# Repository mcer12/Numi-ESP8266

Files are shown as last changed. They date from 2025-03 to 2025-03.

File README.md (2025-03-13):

# Numi-ESP8266
Numi is an open source ESP8266 numitron clock. It's designed to be as low profile as possible, powered using USB-PD.

**Wiki**  
Software-wise it is based on my Flora-ESP8266 project, so you can head over there for basic info.  
https://github.com/mcer12/Flora-ESP8266/wiki/

**Enclosure**  
You can find the designs in this repository inside "3D" folder or download them on printables  
https://www.printables.com/model/1228268

**Some things to note:**
1) This design is made with small footprint and ultra low-profile in mind, using only 3mm high components.
2) Using mostly modern and widely available components.
3) Can be completely sourced from LCSC (except for the VFDs and incadescent bulb) and partially assembled using JLCPCB assembly service.
4) CH340 with NodeMCU style auto-reset built-in for easy programming / debugging via USB-C
5) Each segment driven directly, not multiplexed
6) NTP based, no battery / RTC. Connect to wifi and you're done.
7) Simple and easy to set up, mobile-friendly web interface
8) diyHue and remote control support
9) 3 levels of brightness + optional low brightness night mode
10) No buttons design. Simple configuration portal is used for settings.
11) Daylight saving (summer time) support built in and super simple to set up.

**License:**  
GPL-3.0 License  
LGPL-2.1 License (modified SPI library)  
Mozilla Public License 2.0 (iro.js, https://github.com/jaames/iro.js)

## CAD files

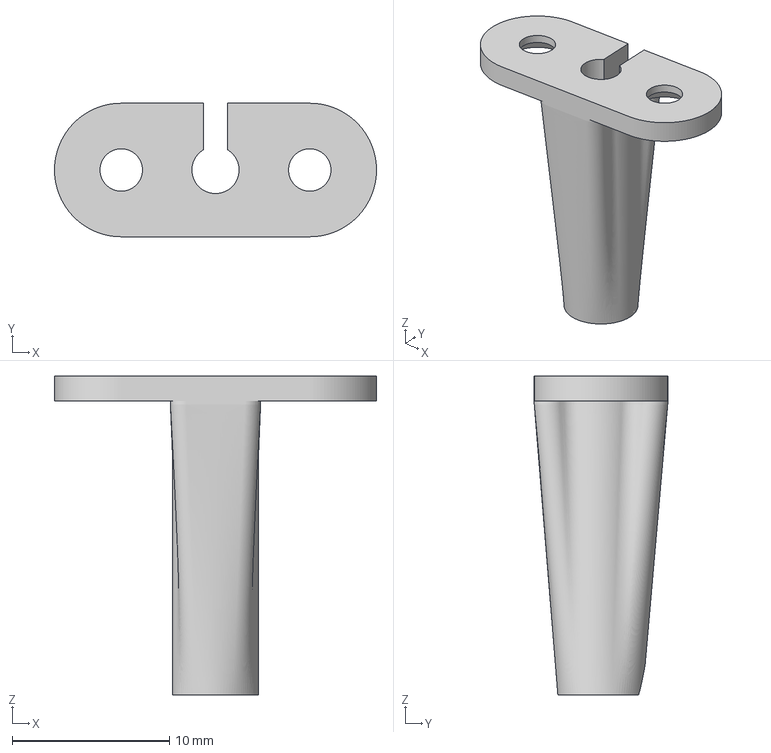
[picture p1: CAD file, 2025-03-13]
3D/numi_colon.3mf
20.5 x 8.50 x 20.3 mm

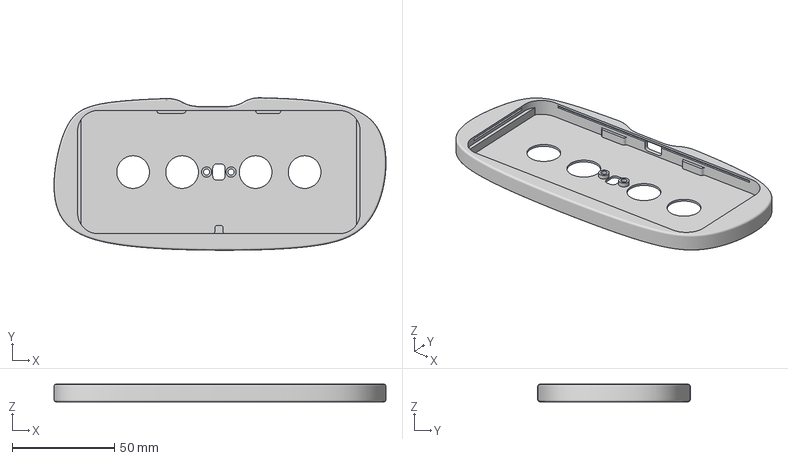
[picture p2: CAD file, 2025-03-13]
3D/numi_top.3mf
162.6 x 74.7 x 8.60 mm

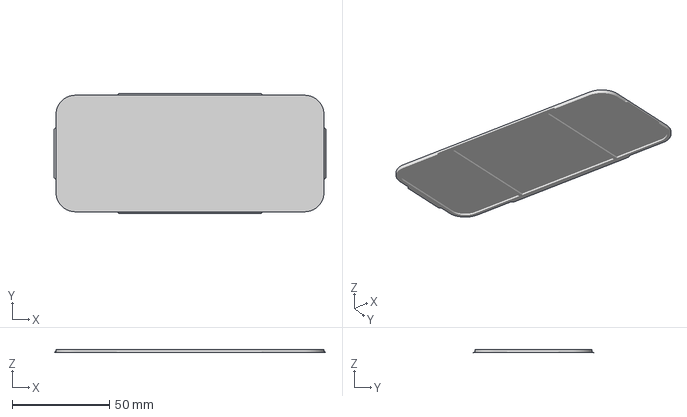
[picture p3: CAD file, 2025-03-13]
3D/numi_bottom.3mf
140.0 x 62.0 x 1.80 mm

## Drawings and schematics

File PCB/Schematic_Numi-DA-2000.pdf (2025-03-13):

AW21036

## CYPD3177 Power Switch

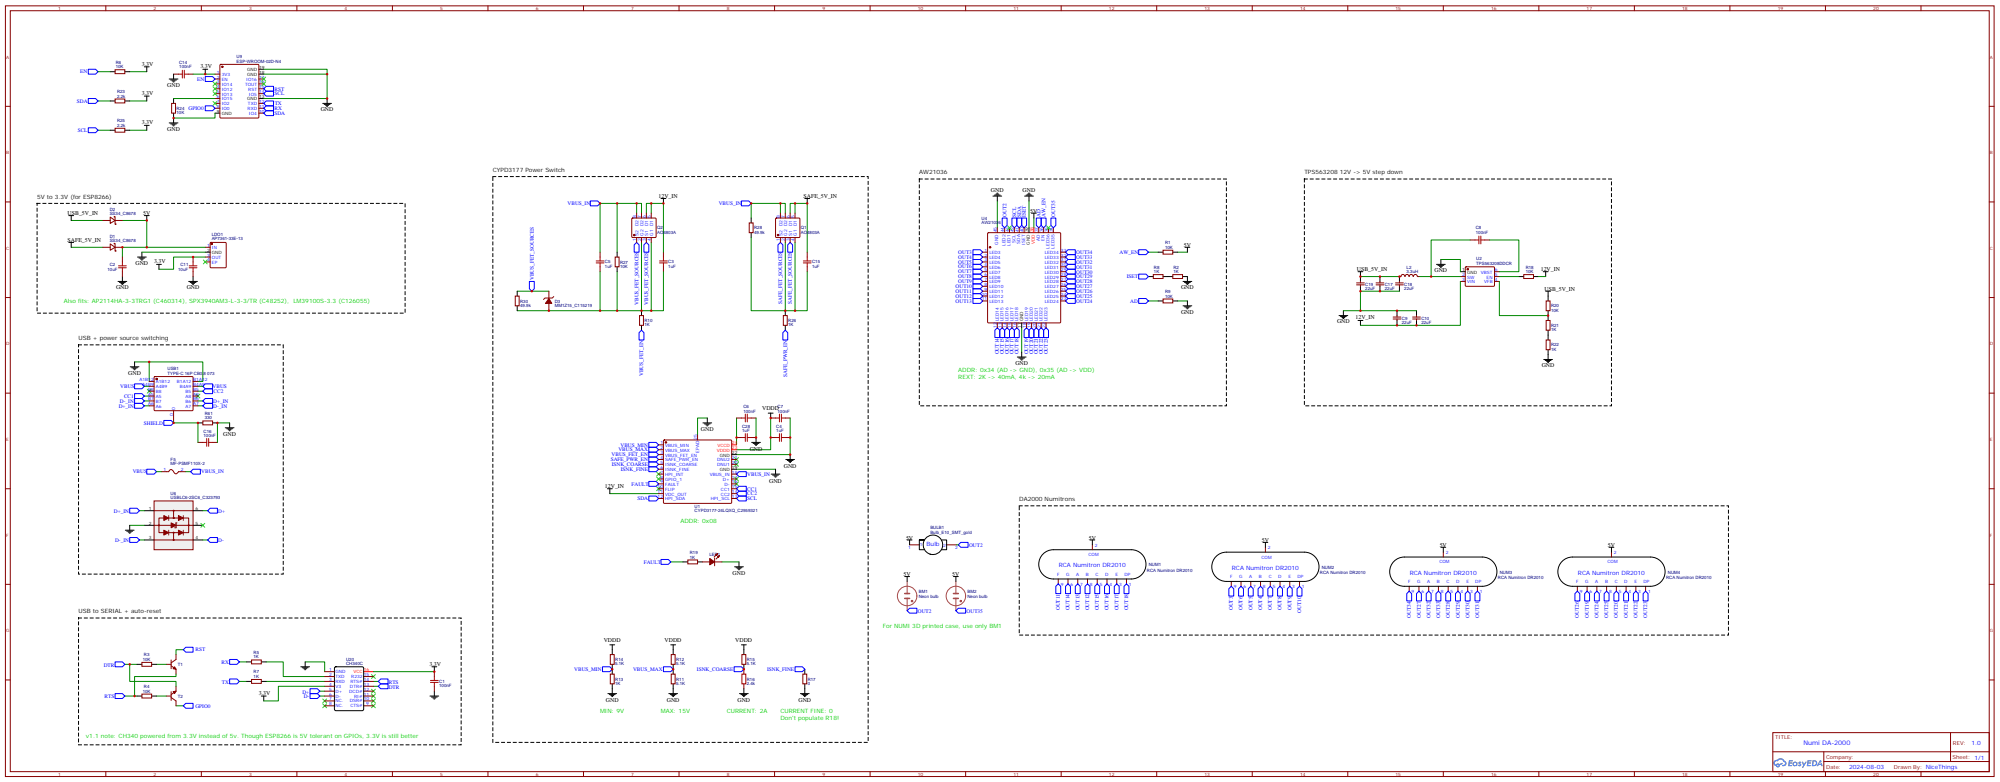
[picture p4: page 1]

USB + power source switching

ADDR: 0x34 (AD -> GND), 0x35 (AD -> VDD)
REXT: 2K -> 40mA, 4k -> 20mA

USB to SERIAL + auto-reset

For NUMI 3D printed case, use only BM1

v1.1 note: CH340 powered from 3.3V instead of 5v. Though ESP8266 is 5V tolerant on GPIOs, 3.3V is still better

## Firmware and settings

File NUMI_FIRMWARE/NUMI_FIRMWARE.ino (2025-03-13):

/*
   GNU General Public License v3.0
   Copyright (c) 2021 Martin Cerny
*/

#include <FS.h>
#include <ArduinoJson.h>
#include <math.h>

#include <ESP8266WiFi.h>
#include <ESP8266HTTPClient.h>
#include <WiFiClient.h>
#include <DNSServer.h>
#include <ESP8266mDNS.h>
#include <WiFiUdp.h>
#include <ESP8266WebServer.h>
#include <ESP8266HTTPUpdateServer.h>
#include <WiFiUdp.h>
#include <Ticker.h>

#include <Wire.h>
#include <AW210xx.h>

#include <NeoPixelBus.h>
#include <NeoPixelAnimator.h>

#include <TimeLib.h>
#include <Timezone.h>

// Pick a clock version below!
#define CLOCK_VERSION_IV6
//#define CLOCK_VERSION_IV6_V2
//#define CLOCK_VERSION_IV3
//#define CLOCK_VERSION_IV12
//#define CLOCK_VERSION_IV22

#if !defined(CLOCK_VERSION_IV6) && !defined(CLOCK_VERSION_IV6_V2) && !defined(CLOCK_VERSION_IV3) && !defined(CLOCK_VERSION_IV12) && !defined(CLOCK_VERSION_IV22)
#error "You have to select a clock version! Line 25"
#endif

#define AP_NAME "NUMI_"
#define FW_NAME "NUMI"
#define FW_VERSION "1.0.0"
#define CONFIG_TIMEOUT 300000 // 300000 = 5 minutes

// ONLY CHANGE DEFINES BELOW IF YOU KNOW WHAT YOU'RE DOING!
#define NORMAL_MODE 0
#define OTA_MODE 1
#define CONFIG_MODE 2
#define CONFIG_MODE_LOCAL 3
#define CONNECTION_FAIL 4
#define UPDATE_SUCCESS 1
#define UPDATE_FAIL 2
#define DATA 13
#define CLOCK 14
#define LATCH 15
#define TIMER_INTERVAL_uS 200 // 200 = safe value for 6 digits. You can go down to 150 for 4-digit one. Going too low will cause crashes.

// User global vars
const char* dns_name = "numi"; // only for AP mode
const char* update_path = "/update";
const char* update_username = "numi";
const char* update_password = "numi";
const char* ntpServerName = "pool.ntp.org";

const int dotsAnimationSteps = 2000; // dotsAnimationSteps * TIMER_INTERVAL_uS = one animation cycle time in microseconds

const uint8_t PixelCount = 14; // Addressable LED count

HsbColor red[] = {
  HsbColor(RgbColor(100, 0, 0)), // LOW
  HsbColor(RgbColor(150, 0, 0)), // MEDIUM
  HsbColor(RgbColor(200, 0, 0)), // HIGH
};
HsbColor green[] = {
  HsbColor(RgbColor(0, 100, 0)), // LOW
  HsbColor(RgbColor(0, 150, 0)), // MEDIUM
  HsbColor(RgbColor(0, 200, 0)), // HIGH
};
HsbColor blue[] = {
  HsbColor(RgbColor(0, 0, 100)), // LOW
  HsbColor(RgbColor(0, 0, 150)), // MEDIUM
  HsbColor(RgbColor(0, 0, 200)), // HIGH
};
HsbColor yellow[] = {
  HsbColor(RgbColor(100, 100, 0)), // LOW
  HsbColor(RgbColor(150, 150, 0)), // MEDIUM
  HsbColor(RgbColor(200, 200, 0)), // HIGH
};
HsbColor purple[] = {
  HsbColor(RgbColor(100, 0, 100)), // LOW
  HsbColor(RgbColor(150, 0, 150)), // MEDIUM
  HsbColor(RgbColor(200, 0, 200)), // HIGH
};
HsbColor azure[] = {
  HsbColor(RgbColor(0, 100, 100)), // LOW
  HsbColor(RgbColor(0, 150, 150)), // MEDIUM
  HsbColor(RgbColor(0, 200, 200)), // HIGH
};

#if defined(CLOCK_VERSION_IV6) || defined(CLOCK_VERSION_IV6_V2) || defined(CLOCK_VERSION_IV3)
HsbColor colonColorDefault[] = {
  HsbColor(RgbColor(30, 70, 50)), // LOW
  HsbColor(RgbColor(50, 100, 80)), // MEDIUM
  HsbColor(RgbColor(80, 130, 100)), // HIGH
};
#else
HsbColor colonColorDefault[] = {
  HsbColor(RgbColor(30, 70, 50)), // LOW
  HsbColor(RgbColor(50, 100, 80)), // MEDIUM
  HsbColor(RgbColor(120, 220, 140)), // HIGH
};
/*
  RgbColor colonColorDefault[] = {
  RgbColor(30, 70, 50), // LOW
  RgbColor(50, 100, 80), // MEDIUM
  RgbColor(100, 200, 120), // HIGH
  };
*/
#endif

/*
  RgbColor colonColorDefault[] = {
  RgbColor(30, 6, 1), // LOW
  RgbColor(38, 8, 2), // MEDIUM
  RgbColor(50, 10, 2), // HIGH
  };
*/
RgbColor currentColor = RgbColor(0, 0, 0);
//RgbColor colonColorDefault = RgbColor(90, 27, 7);
//RgbColor colonColorDefault = RgbColor(38, 12, 2);

const uint8_t registersCount = 4;
const uint8_t segmentCount = 8;
const uint8_t colonPins[2] = {1, 34};
const uint8_t digitPins[registersCount][segmentCount] = {
  {14, 15, 16, 10, 13, 12, 11, 17}, // C | D | E | F | G | A | B | DOT
  {6, 7, 8, 2, 5, 4, 3, 9},         // C | D | E | F | G | A | B | DOT
  {27, 28, 29, 33, 26, 31, 32, 30}, // C | D | E | F | G | A | B | DOT
  {19, 20, 21, 25, 18, 23, 24, 22}, // C | D | E | F | G | A | B | DOT
};

uint8_t letter_p[8] = {0, 0, 1, 1, 1, 1, 1, 0};
uint8_t letter_i[8] = {0, 0, 1, 1, 0, 0, 0, 0};
uint8_t dot[8] = {0, 0, 0, 0, 0, 0, 0, 1};
uint8_t numbers[10][8] = {
  {1, 1, 1, 1, 0, 1, 1, 0}, // 0 ==>  BR | B | BL | TL | M | T | TR | DOT
  {1, 0, 0, 0, 0, 0, 1, 0}, // 1 ==>  BR | B | BL | TL | M | T | TR | DOT
  {0, 1, 1, 0, 1, 1, 1, 0}, // 2 ==>  BR | B | BL | TL | M | T | TR | DOT
  {1, 1, 0, 0, 1, 1, 1, 0}, // 3 ==>  BR | B | BL | TL | M | T | TR | DOT
  {1, 0, 0, 1, 1, 0, 1, 0}, // 4 ==>  BR | B | BL | TL | M | T | TR | DOT
  {1, 1, 0, 1, 1, 1, 0, 0}, // 5 ==>  BR | B | BL | TL | M | T | TR | DOT
  {1, 1, 1, 1, 1, 1, 0, 0}, // 6 ==>  BR | B | BL | TL | M | T | TR | DOT
  {1, 0, 0, 0, 0, 1, 1, 0}, // 7 ==>  BR | B | BL | TL | M | T | TR | DOT
  {1, 1, 1, 1, 1, 1, 1, 0}, // 8 ==>  BR | B | BL | TL | M | T | TR | DOT
  {1, 1, 0, 1, 1, 1, 1, 0}, // 9 ==>  BR | B | BL | TL | M | T | TR | DOT
};
volatile uint8_t segmentBrightness[registersCount][8];
volatile uint8_t targetBrightness[registersCount][8];

// 32 steps of brightness * 200uS => 6.4ms for full refresh => 160Hz... pretty good!
// 48 steps => 100hz
volatile uint8_t shiftedDutyState[registersCount];
const uint8_t pwmResolution = 48; // should be in the multiples of dimmingSteps to enable smooth crossfade
const uint8_t dimmingSteps = 8;

// MAX BRIGHTNESS PER DIGIT
// These need to be multiples of 8 to enable crossfade! Must be less or equal as pwmResolution.
// Set maximum brightness for reach digit separately. This can be used to normalize brightness between new and burned out tubes.
// Last two values are ignored in 4-digit clock
uint8_t bri_vals_separate[3][6] = {
  {100, 100, 100, 100, 100, 100}, // Low brightness
  {160, 160, 160, 160, 160, 160}, // Medium brightness
  {255, 255, 255, 255, 255, 255}, // High brightness
};
uint8_t bri_vals_colon[3] = {190, 220, 255};


// Better left alone global vars
volatile bool isPoweredOn = true;
unsigned long configStartMillis, prevDisplayMillis;
volatile int activeDot;
uint8_t deviceMode = NORMAL_MODE;
bool timeUpdateFirst = true;
volatile bool toggleSeconds;
bool breatheState;
byte mac[6];
volatile int dutyState = 0;
volatile uint8_t digitsCache[] = {0, 0, 0, 0};
volatile byte bytes[registersCount];
volatile byte prevBytes[registersCount];
volatile uint8_t bri = 0;
volatile uint8_t crossFadeTime = 0;
uint8_t timeUpdateStatus = 0; // 0 = no update, 1 = update success, 2 = update fail,
uint8_t failedAttempts = 0;
volatile bool enableDotsAnimation;
volatile unsigned short dotsAnimationState;
RgbColor colonColor;
IPAddress ip_addr;

AW210xx aw210xx;

TimeChangeRule EDT = {"EDT", Last, Sun, Mar, 1, 120};  //UTC + 2 hours
TimeChangeRule EST = {"EST", Last, Sun, Oct, 1, 60};  //UTC + 1 hours
Timezone TZ(EDT, EST);
NeoPixelBus<NeoGrbFeature, NeoWs2813Method> strip(PixelCount);
NeoGamma<NeoGammaTableMethod> colorGamma;
NeoPixelAnimator animations(PixelCount);
DynamicJsonDocument json(2048); // config buffer
Ticker fade_animation_ticker;
Ticker onceTicker;
Ticker colonTicker;
DNSServer dnsServer;
ESP8266WebServer server(80);
WiFiUDP Udp;
ESP8266HTTPUpdateServer httpUpdateServer;
unsigned int localPort = 8888;  // local port to listen for UDP packets


// the setup function runs once when you press reset or power the board
void setup() {
  // initialize digital pin LED_BUILTIN as an output.
  Serial.begin(115200);
  Serial.println("");

  if (!SPIFFS.begin()) {
    Serial.println("[CONF] Failed to mount file system");
  }
  readConfig();

  initScreen();

  WiFi.macAddress(mac);

  const char* ssid = json["ssid"].as<const char*>();
  const char* pass = json["pass"].as<const char*>();
  const char* ip = json["ip"].as<const char*>();
  const char* gw = json["gw"].as<const char*>();
  const char* sn = json["sn"].as<const char*>();

  if (ssid != NULL && pass != NULL && ssid[0] != '\0' && pass[0] != '\0') {
    Serial.println("[WIFI] Connecting to: " + String(ssid));
    WiFi.mode(WIFI_STA);

    if (ip != NULL && gw != NULL && sn != NULL && ip[0] != '\0' && gw[0] != '\0' && sn[0] != '\0') {
      IPAddress ip_address, gateway_ip, subnet_mask;
      if (!ip_address.fromString(ip) || !gateway_ip.fromString(gw) || !subnet_mask.fromString(sn)) {
        Serial.println("[WIFI] Error setting up static IP, using auto IP instead. Check your configuration.");
      } else {
        WiFi.config(ip_address, gateway_ip, subnet_mask);
      }
    }
    // serializeJson(json, Serial);

    enableDotsAnimation = true; // Start the dots animation

    WiFi.hostname(AP_NAME + macLastThreeSegments(mac));
    WiFi.begin(ssid, pass);

    //startBlinking(200, colorWifiConnecting);

    for (int i = 0; i < 1000; i++) {
      if (WiFi.status() != WL_CONNECTED) {
        if (i > 200) { // 20s timeout
          enableDotsAnimation = false;
          deviceMode = CONFIG_MODE;
          Serial.print("[WIFI] Failed to connect to: " + String(ssid) + ", going into config mode.");
          delay(500);
          break;
        }
        delay(100);
      } else {
        enableDotsAnimation = false;
        Serial.print("[WIFI] Successfully connected to: ");
        Serial.println(WiFi.SSID());
        Serial.print("[WIFI] Mac address: ");
        Serial.println(WiFi.macAddress());
        Serial.print("[WIFI] IP address: ");
        Serial.println(WiFi.localIP());
        delay(1000);
        break;
      }
    }
  } else {
    deviceMode = CONFIG_MODE;
    Serial.println("[CONF] No credentials set, going to config mode.");
  }

  if (deviceMode == CONFIG_MODE || deviceMode == CONNECTION_FAIL) {
    startConfigPortal(); // Blocking loop
  } else {
    ndp_setup();
    startServer();
  }

  //initScreen();

  if (json["rst_cycle"].as<unsigned int>() == 1) {
    cycleDigits();
    delay(500);
  }

  if (json["rst_ip"].as<unsigned int>() == 1) {
    showIP();
    delay(5000);
  }

  /*
    if (!MDNS.begin(dns_name)) {
      Serial.println("[ERROR] MDNS responder did not setup");
    } else {
      Serial.println("[INFO] MDNS setup is successful!");
      MDNS.addService("http", "tcp", 80);
    }
  */
}

// the loop function runs over and over again forever
void loop() {

  if (timeUpdateFirst == true && timeUpdateStatus == UPDATE_FAIL || deviceMode == CONNECTION_FAIL) {
    setAllDigitsTo(0);
    delay(10);
    return;
  }

  if (millis() - prevDisplayMillis >= 1000) { //update the display only if time has changed
    prevDisplayMillis = millis();
    toggleNightMode();

    if (timeUpdateStatus) {
      if (timeUpdateStatus == UPDATE_SUCCESS) {
        //setTemporaryColonColor(5, green[bri]);
      }
      if (timeUpdateStatus == UPDATE_FAIL) {
        if (failedAttempts > 2) {
          colonColor = red[bri];
        } else {
          //setTemporaryColonColor(5, red[bri]);
        }
      }
      timeUpdateStatus = 0;
    }

    handleColon();
    showTime();
  }

  //MDNS.update();
  server.handleClient();
  delay(1); // Keeps the ESP cold!

}

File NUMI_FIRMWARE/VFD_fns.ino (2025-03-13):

void initScreen() {

  bri = json["bri"].as<int>();
  crossFadeTime = json["fade"].as<int>();
  //setupCrossFade();
  //aw210xx.begin(ADDR_AW, I2C_SPEED, FREQ_2K, true); // Address, I2C speed in hz, pwm frequency, phase shift enable/disable
  aw210xx.begin();
  aw210xx.setFreq(FREQ_62K); // set frequency, see accepted values in the comment above setup()

  for (int ii = 0; ii < 36; ii++) {
    aw210xx.setCol(ii, 255);
    aw210xx.setBri(ii, 0);
  }
  aw210xx.setGlobalBri(255); // global brightness setting, accepts values 0-255
  aw210xx.update();

  uint8_t verValue = aw210xx.readRegister(REG_RESET);
  Serial.print("Chip id: ");
  Serial.println(verValue, HEX);

  //ITimer.attachInterruptInterval(TIMER_INTERVAL_uS, TimerHandler);
  // 30ms slow 240ms, 20 => medium 160ms, 15 => quick 120ms

  blankAllDigits();
}

void enableScreen() {
  //ITimer.attachInterruptInterval(TIMER_INTERVAL_uS, TimerHandler);
}
void disableScreen() {
  //ITimer.detachInterrupt();
}

/*
  void setupCrossFade() {
  if (crossFadeTime > 0) {
    fade_animation_ticker.attach_ms(crossFadeTime, handleFade); // handle dimming animation
  } else {
    fade_animation_ticker.attach_ms(20, handleFade); // handle dimming animation
  }
  }
  void handleFade() {
  for (int i = 0; i < registersCount; i++) {
    for (int ii = 0; ii < segmentCount; ii++) {
      if (targetBrightness[i][ii] > bri_vals_separate[bri][i]) targetBrightness[i][ii] = bri_vals_separate[bri][i];

      if (crossFadeTime > 0) {
        if (targetBrightness[i][ii] > segmentBrightness[i][ii]) {
          segmentBrightness[i][ii] += bri_vals_separate[bri][i] / dimmingSteps;
          if (segmentBrightness[i][ii] > bri_vals_separate[bri][i]) segmentBrightness[i][ii] = bri_vals_separate[bri][i];
        } else if (targetBrightness[i][ii] < segmentBrightness[i][ii]) {
          segmentBrightness[i][ii] -= bri_vals_separate[bri][i] / dimmingSteps;
          if (segmentBrightness[i][ii] < 0) segmentBrightness[i][ii] = 0;
        }
      } else {
        segmentBrightness[i][ii] = targetBrightness[i][ii];
      }
    }
  }
  aw210xx.update();

  }
*/

void handleColon() {
  // 0 = off, 1 = always on, 2 = ON/OFF each second, 3 = always on with gradient
  if (json["colon"].as<int>() == 0) {
    aw210xx.setBri(colonPins[0], 0);
    aw210xx.setBri(colonPins[1], 0);
    aw210xx.update();
    return;
  } else if (json["colon"].as<int>() == 1 || json["colon"].as<int>() == 3) {
    aw210xx.setBri(colonPins[0], bri_vals_colon[bri]);
    aw210xx.setBri(colonPins[1], bri_vals_colon[bri]);
    aw210xx.update();
    return;
  } else if (json["colon"].as<int>() == 2) {
    if (toggleSeconds) {
      aw210xx.setBri(colonPins[0], bri_vals_colon[bri]);
      aw210xx.setBri(colonPins[1], bri_vals_colon[bri]);
    }
    else {
      aw210xx.setBri(colonPins[0], 0);
      aw210xx.setBri(colonPins[1], 0);
    }
    toggleSeconds = !toggleSeconds;
    aw210xx.update();
    return;
  }
}

void setDigit(uint8_t digit, uint8_t value) {
  draw(digit, numbers[value]);
}

void setAllDigitsTo(uint16_t value) {
  for (int i = 0; i < registersCount; i++) {
    setDigit(i, value);
  }
}

void blankDigit(uint8_t digit) {
  for (int i = 0; i < segmentCount; i++) {
    aw210xx.setBri(digitPins[digit][i], 0);
  }
  aw210xx.update();
}

void blankAllDigits() {
  for (int i = 0; i < registersCount; i++) {
    blankDigit(i);
  }
}

void setDot(uint8_t digit, bool enable) {

}

void draw(uint8_t digit, uint8_t value[segmentCount]) {
  for (int i = 0; i < segmentCount; i++) {
    if (value[i] == 1) {
      //targetBrightness[digit][i] = bri_vals_separate[bri][digit];
      aw210xx.setBri(digitPins[digit][i], bri_vals_separate[bri][digit]);

    } else {
      //targetBrightness[digit][i] = 0;
      aw210xx.setBri(digitPins[digit][i], 0);
    }
  }
  aw210xx.update();

}

void showTime() {

  int hours = hour();
  if (hours > 12 && json["t_format"].as<int>() == 0) { // 12 / 24 h format
    hours -= 12;
  } else if (hours == 0 && json["t_format"].as<int>() == 0) {
    hours = 12;
  }

  int splitTime[6] = {
    (hours / 10) % 10,
    hours % 10,
    (minute() / 10) % 10,
    minute() % 10,
    (second() / 10) % 10,
    second() % 10,
  };

  for (int i = 0; i < registersCount ; i++) {
    if (i == 0 && splitTime[0] == 0 && json["zero"].as<int>() == 0) {
      blankDigit(i);
      continue;
    }
    setDigit(i, splitTime[i]);
  }

}

void cycleDigits() {
  for (int i = 0; i < 10; i++) {
    for (int ii = 0; ii < registersCount; ii++) {
      setDigit(ii, i);
    }
    delay(1000);
  }
}

void showIP() {
  IPAddress ip_addr = WiFi.localIP();

  if (registersCount < 6) {
    blankDigit(0);
    if ((ip_addr[3] / 100) % 10 == 0) {
      blankDigit(1);
    } else {
      setDigit(1, (ip_addr[3] / 100) % 10);
    }
    if ((ip_addr[3] / 10) % 10 == 0) {
      blankDigit(2);
    } else {
      setDigit(2, (ip_addr[3] / 10) % 10);
    }
    setDigit(3, (ip_addr[3]) % 10);
  } else {
    setDigit(0, 1);
    draw(1, letter_p);
    blankDigit(2);
    if ((ip_addr[3] / 100) % 10 == 0) {
      blankDigit(3);
    } else {
      setDigit(3, (ip_addr[3] / 100) % 10);
    }
    if ((ip_addr[3] / 10) % 10 == 0 && (ip_addr[3] / 100) % 10 == 0) {
      blankDigit(4);
    } else {
      setDigit(4, (ip_addr[3] / 10) % 10);
    }
    setDigit(5, (ip_addr[3]) % 10);
  }


}

void toggleNightMode() {
  if (json["nmode"].as<int>() == 0) return;
  if (hour() >= 22 || hour() <= 6) {
    bri = 0;
  } else {
    bri = json["bri"].as<int>();
  }
}
